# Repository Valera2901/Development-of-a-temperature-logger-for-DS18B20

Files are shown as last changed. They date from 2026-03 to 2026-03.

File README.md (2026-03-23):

# Development-of-a-temperature-logger-for-DS18B20

Организовать мониторинг температуры в геофизической обсерватории (на примере обсерватории Арти Института геофизики УрО РАН).
Создать устройство на основе микроконтроллера, к которому подключаются несколько температурных датчиков (DS18B20), расположенных в разных местах (вне помещения, внутри помещения, подключен к корпусу измерительного прибора и тд). Устройство должно функционировать автономно, без подключения к компьютеру. При включении питания, устройство должно автоматически записывать принимаемые данные с термодатчиков в файл на SD-карту. Скачивание данных можно организовать несколькими способами: 

1\. при нахождении в сети вайфай контроллер мог бы передавать данные на определенный сайт, 

2\. Можно подключить к микроконтроллеру плату LAN и подключить к локальной сети обсерватории, чтобы данные были доступны как обычный диск в сети.
Проект выполнен на 50% если реализованы следующие функции:
Запись результатов измерений на SD‑карту (без потерь).
Обеспечение актуального точного времени на часах при записи данных в файле
Проект выполнен на 75% если реализованы следующие функции:
Запись результатов измерений на SD‑карту (без потерь).
Обеспечение актуального точного времени на часах при записи данных в файле
просмотр и скачивание файлов данных, без необходимости прерывать измерения (wifi, bt, LAN, веб-интерфейс, сетевой диск, обоснованный выбор командой)
Проект выполнен на 100% если реализованы следующие функции:
Запись результатов измерений на SD‑карту (без потерь).
Обеспечение актуального точного времени на часах при записи данных в файле
просмотр и скачивание файлов данных, без необходимости прерывать измерения (wifi, bt, LAN, веб-интерфейс, сетевой диск, обоснованный выбор командой)
просмотр результатов текущих измерений. Выбрать удобный способ для этого (мобильное приложение, веб-интерфейс)

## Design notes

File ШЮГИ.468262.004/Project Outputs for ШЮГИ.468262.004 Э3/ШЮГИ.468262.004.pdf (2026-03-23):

| | ¹ äîêóì. | Ïîäï. | Äàòà | ØÞÃÈ.468262.004 Èçì. Ëèñò
Ðàçðàá. | Âøèâöåâ | | | Ëîããåð òåìïåðàòóðíûé | Ëèò. | Ëèñò | Ëèñòîâ
Ïðîâ. | | | | | | | | 1

Í.êîíòð.
Óòâ.

Äîêóìåíòàöèÿ

*) | ØÞÃÈ.468262.004 Ý3 | Ñõåìà ýëåêòðè÷åñêàÿ | *)A2, A4
| | ïðèíöèïèàëüíàÿ
À3 | ØÞÃÈ.468262.004 Ý4 | Ñõåìà ýëåêòðè÷åñêàÿ
| | ñîåäèíåíèé
À4 | ØÞÃÈ.468262.004 ÏÝ3 | Ïåðå÷åíü ýëåìåíòîâ
À4 | ØÞÃÈ.468262.004 ÏÇ | Ïîÿñíèòåëüíàÿ çàïèñêà
| ØÞÃÈ.468262.004 Ò12Ì | Äàííûå ïðîãðàììèðîâàíèÿ

Ñáîðî÷íûå åäèíèöû

À4 | 1 | ØÞÃÈ.685711.470 | Êàáåëü 1-wire | 3
A4 | 2 ØÞÃÈ.758724.220 | | Ìîäóëü âû÷èñëèòåëüíûé | 1
A4 | 3 ØÞÃÈ.758724.224 | | Ìîäóëü äàò÷èêà | 1
| 4 ØÞÃÈ.758724.224-01 | | Ìîäóëü äàò÷èêà | 1
| 5 ØÞÃÈ.758724.224-02 | | Ìîäóëü äàò÷èêà | 1

Ôîðìàò
Çîíà
Ïîç.
Îáîçíà÷åíèå | Íàèìåíîâàíèå

Êîë.

Ïðèìå-
÷àíèå
Êîïèðîâàë | Ôîðìàò A4

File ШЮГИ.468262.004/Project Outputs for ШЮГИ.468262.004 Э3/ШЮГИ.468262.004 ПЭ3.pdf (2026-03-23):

## ØÞÃÈ.468262.004 ÏÝ3

Èçì. Ëèñò | | ¹ äîêóì. | Ïîäï. | Äàòà
Ðàçðàá. | Âøèâöåâ | | | Ëîããåð òåìïåðàòóðíûé Ïåðå÷åíü ýëåìåíòîâ | Ëèò. | Ëèñò | Ëèñòîâ
Ïðîâ. | | | | | | | | 1 | 4

Í.êîíòð.
Óòâ.
A1 | Óñòðîéñòâî FJM10K YDELEKS | 1
| Êîíäåíñàòîðû 0603 Thunder
| Êîíäåíñàòîðû JCK JB Capacitors
C1, C2 0603B104J500CT | | 2
C3 | JCK1E100M050054 | 1
C4 | JCK1E470M063054 | 1
C5...C7 0603B104J500CT | | 3
C8 | JCK1E220M063054 | 1
C9 | JCK1C221M080105 | 1
C10...C14 0603B104J500CT | | 5
| Ìèêðîñõåìû
DA1 | XL6009E1 Shanghai Xinlong
| Semiconductor Technology Co., Ltd | 1
DD1 | ESP32-S3-WROOM1 MON16R8 Espressif | 1
DD2 | PCF8574T Philips Semiconductors | 1
DD3 | NEO-6M U-Blox | 1
DD4 | DS3231S# Maxim Integrated Products | 1
DD5 | 24AA32AT-I/ST Microchip Technology | 1

G1, G2 Ýëåìåíò ïèòàíèÿ ëèòèåâûé GPCR2032-7C1
| GP batteries | 2
| Îïòîýëåêòðîíèêà
HG1 | BCB2004-03-LW-SNMWD Blaze Display Technology | 1
HL1 | FYLS-0603GC Ningbo Foryard Optoelectronics | 1

Ïîç.
îáîçíà-
÷åíèå
Íàèìåíîâàíèå | Êîë. Ïðèìå÷àíèå

## ØÞÃÈ.468262.004 ÏÝ3

Ëèñò
2 Èçì. Ëèñò | ¹ äîêóì. | Ïîäï. | Äàòà
| Êàòóøêè èíäóêòèâíîñòè
L1 | 7448991470 Wurth Elektronik | 1
L2 | LQM21DN220N00L Murata Electronics | 1
| Ðåçèñòîðû Ð1-12 ÀÁØÊ.434110.023 ÒÓ
| Ðåçèñòîðû ÍÐ1-86-6 ØÊÀÁ.434110.039 ÒÓ
| Ðåçèñòîðû 3362P Bourns
R1...R3 Ð1-12-0,063-10 êOì±2 %-Ò-Ë-Ì | | 3
R4 | ÍÐ1-86-6-10 êÎì±1 %-Ì-"À" | 1
R5 | Ð1-12-0,063-10 êOì±2 %-Ò-Ë-Ì | 1
R6 | Ð1-12-0,063-86,6 êOì±2 %-Ò-Ë-Ì | 1
R7 | ÍÐ1-86-6-10 êÎì±1 %-Ì-"À" | 1
R8 | 3362P-1-103LF | 1
R9, R10 Ð1-12-0,063-22,1 Oì±2 %-Ò-Ë-Ì | | 1
R11 | Ð1-12-0,063-1 êOì±2 %-Ò-Ë-Ì | 1
R12 | Ð1-12-0,125-22,1 Oì±2 %-Ò-Ë-Ì | 1
R13 | Ð1-12-0,063-1 êOì±2 %-Ò-Ë-Ì | 1
R14 | ÍÐ1-86-6-10 êÎì±1 %-Ì-"À" | 1
R15 | Ð1-12-0,063-1 êOì±2 %-Ò-Ë-Ì | 1
| Âûêëþ÷àòåëè
SA1 | MTS-103-C3 Massuse Ltd. | 1
SB1, SB2 KLS7-TS3401-2.5-250-B
| KLS Electronics Co., Ltd. | 2
| Äèîäû
VD1 | VS-50WQ03FN-M3 Vishay Intertechnology Inc. 1
VD2, VD3 LL4148 Diotec Semiconductor | | 1
VT1 | Òðàíçèñòîð BC847 NXP Semiconductors | 1

| | | 3 Èçì. Ëèñò
¹ äîêóì. | Ïîäï. | Äàòà
WA1 | Àíòåííà GNSS Ceramic Antenna Waveshare
| International Limited | 1
| Ñîåäèíåíèÿ êîíòàêòíûå
X1 | DS1069-4MRW6XB Connfly electronic | 1
X2 | 1050017-0001 Molex | 1
X3 | DS-261A-PA9T-NB-210 Dragon City Industries | 1
X4 | TFP09-2-12B Shenzhen Chipskey Technology Co., Ltd. 1
X5 | DS-261A-PA9T-NB-210 Dragon City Industries | 1
A1, A2 1 Ïîíèæàþùèé ïðåîáðàçîâàòåëü íàïðÿæåíèÿ | 2
| Êîíäåíñàòîðû
C15 | 0603B104J500CT Thunder | 1
C16 | 0603B561J500CT Thunder | 1
C17 | JCK1C100M040054 JB Capacitors | 1
DA2 | Ìèêðîñõåìà MC34063ADG ON Semiconductor | 1
L3 | Êàòóøêà èíäóêòèâíîñòè CDRH74NP-101MC-B
| SUMIDA CORPORATION | 1
| Ðåçèñòîðû
R16 | CRL1206-FW-R220ELF Bourns | 1
R17 | Ð1-12-0,25-1,21 êOì±2 %-Ò-Ë-Ì
| ÀÁØÊ.434110.023 ÒÓ | 1
R18 | Ð1-12-0,25-3,65 êOì±2 %-Ò-Ë-Ì
| ÀÁØÊ.434110.023 ÒÓ | 1
VD4 | Äèîä 10MQ040 Sunmate Electronics | 1

| | | 4 Èçì. Ëèñò
¹ äîêóì. | Ïîäï. | Äàòà
A3...A5 2 Ìîäóëü äàò÷èêà | 3
C18 | Êîíäåíñàòîð 0603B104J500CT Thunder | 1
DD6 | Ìèêðîñõåìà DS18B20
| UTD Semiconductor Co.,Ltd | 1

X6, X7 Ñîåäèíåíèå êîíòàêòíîå DS1021-01-1*3SSF112
| Connfly electronic | 2

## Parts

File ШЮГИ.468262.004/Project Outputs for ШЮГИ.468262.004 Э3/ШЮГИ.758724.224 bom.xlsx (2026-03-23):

Line # | Designator | Quantity | ТИП | ValueBOM
 | A3_C18, A4_C18, A5_C18 | 3 | Конденсатор | 0603B104J500CT Thunder
 | A3_DD6, A4_DD6, A5_DD6 | 3 | Микросхема | DS18B20 UTD Semiconductor Co.,Ltd
 | A3_X7, A4_X7, A5_X7 | 6 | Соединитель | DS1021-01-1*3SSF112 Connfly electronic

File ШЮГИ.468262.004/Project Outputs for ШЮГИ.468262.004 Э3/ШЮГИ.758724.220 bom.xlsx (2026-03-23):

Line # | Designator | Quantity | ТИП | ValueBOM | Type2
10 | A1 | 1 | Устройтсво | KY-023 Aitewin Robot | A
11 | A1_C15, A2_C15, C1, C2, C5...C7, C10...C14 | 12 | Конденсатор | 0603B104J500CT Thunder | C
12 | A1_C16, A2_C16 | 2 | Конденсатор | 0603B561J500CT Thunder | C
13 | A1_C17, A2_C17 | 2 | Конденсатор | JCK1C100M040054 JB Capacitors | C
14 | C9 | 1 | Конденсатор | JCK1C221M080105 JB Capacitors | C
15 | C3 | 1 | Конденсатор | JCK1E100M050054 JB Capacitors | C
16 | C8 | 1 | Конденсатор | JCK1E220M063054 JB Capacitors | C
17 | C4 | 1 | Конденсатор | JCK1E470M063054 JB Capacitors | C
18 | DD5 | 1 | Микросхема | 24AA32AT-I/ST Microchip Technology | D
19 | DD4 | 1 | Микросхема | DS3231S# Maxim Integrated Products | D
20 | DD1 | 1 | Микросхема | ESP32-S3-WROOM1 MON16R8 Espressif | D
21 | A1_DA2, A2_DA2 | 2 | Микросхема | MC34063ADG ON Semiconductor | D
22 | DD3 | 1 | Микросхема | NEO-6M U-Blox | D
23 | DD2 | 1 | Микросхема | PCF8574T Philips Semiconductors | D
24 | DA1 | 1 | Микросхема | XL6009E1 Shanghai Xinlong Semiconductor Technology Co., Ltd | D
25 | G1, G2 | 2 | Батарейка | GPCR2032-7C1 GP Batteries | G
26 | HG1 | 1 | Оптоэлектроника | BCB2004-03-LW-SNMWD Blaze Display Technology | H
27 | HL1 | 1 | Оптоэлектроника | FYLS-0603GC Ningbo Foryard Optoelectronics | H
28 | L1 | 1 | Дроссель | 7448991470 Würth Elektronik | L
29 | A1_L3, A2_L3 | 2 | Дроссель | CDRH74NP-101MC-B SUMIDA CORPORATION | L
30 | L2 | 1 | Дроссель | LQM21DN220N00L Murata Electronics | L
31 | R8 | 1 | Резистор | 3362P-1-103LF Bourns | R
32 | A1_R16, A2_R16 | 2 | Резистор | CRL1206-FW-R220ELF Bourns | R
33 | R4, R7, R14 | 3 | Резистор | НР1-86-6-10 кОм±1 %-М-«А» ШКАБ.434110.039 ТУ | R
34 | R11, R13, R15 | 3 | Резистор | Р1-12-0,063-1 кОм±2 %-Т-Л-М АБШК.434110.023 ТУ | R
35 | R1...R3, R5 | 4 | Резистор | Р1-12-0,063-10 кОм±2 %-Т-Л-М АБШК.434110.023 ТУ | R
36 | R9, R10 | 2 | Резистор | Р1-12-0,063-22,1 Ом±2 %-Т-Л-М АБШК.434110.023 ТУ | R
37 | R6 | 1 | Резистор | Р1-12-0,063-86,6 кОм±2 %-Т-Л-М АБШК.434110.023 ТУ | R
38 | R12 | 1 | Резистор | Р1-12-0,125-22,1 Ом±2 %-Т-Л-М АБШК.434110.023 ТУ | R
39 | A1_R17 | 1 | Резистор | Р1-12-0,25-1,21 кОм±2 %-Т-Л-М АБШК.434110.023 ТУ | R
40 | A1_R18 | 1 | Резистор | Р1-12-0,25-3,65 кОм±2 %-Т-Л-М АБШК.434110.023 ТУ | R
41 | A2_R17 | 1 | Резистор | Р1-12-0,25-1 кОм±2 %-Т-Л-М АБШК.434110.023 ТУ | R
42 | A2_R18 | 1 | Резистор | Р1-12-0,25-1,65 кОм±2 %-Т-Л-М АБШК.434110.023 ТУ | R
43 | SB1, SB2 | 2 | Выключатели | KLS7-TS3401-2.5-250-B KLS Electronics Co., Ltd. | S
44 | SA1 | 1 | Выключатели | MTS-103-C3 Massuse Ltd. | S
45 | A1_VD4, A2_VD4 | 2 | Полупроводник | 10MQ040 Sunmate Electronics | V
46 | VT1 | 1 | Полупроводник | BC847 NXP Semiconductors | V
47 | VD2, VD3 | 2 | Полупроводник | LL4148 Diotec Semiconductor | V
48 | VD1 | 1 | Полупроводник | VS-50WQ03FN-M3 Vishay Intertechnology Inc. | V
49 | WA1 | 1 | Антенна | GNSS Ceramic Antenna Waveshare International Limited | W
50 | X2 | 1 | Соединитель | 1050017-0001 Molex | X
51 | A3_X6, A4_X6, A5_X6 | 3 | Соединитель | DS1021-01-1*3SSF112 Connfly electronic | X
52 | XH1 | 1 | Соединитель | DS1021-1*16SF11-B Connfly electronic | X
53 | XH2 |  | Соединитель | DS1023-1*16S21 Connfly electronic | X
54 | X1 | 1 | Соединитель | DS1069-4MRW6XB Connfly electronic | X
55 | X3, X5 | 2 | Соединитель | DS-261A-PA9T-NB-210 Dragon City Industries | X
56 | XG1, XG2 | 2 | Соединитель | KLS5-CR2032-01 KLS electronic co ltd | X
57 | X4 | 1 | Соединитель | TFP09-2-12B Shenzhen Chipskey Technology Co., Ltd. | X
58 | XW1 | 1 | Соединитель | U.FL-R-SMT-1 HIROSE ELECTRIC CO., LTD. | X

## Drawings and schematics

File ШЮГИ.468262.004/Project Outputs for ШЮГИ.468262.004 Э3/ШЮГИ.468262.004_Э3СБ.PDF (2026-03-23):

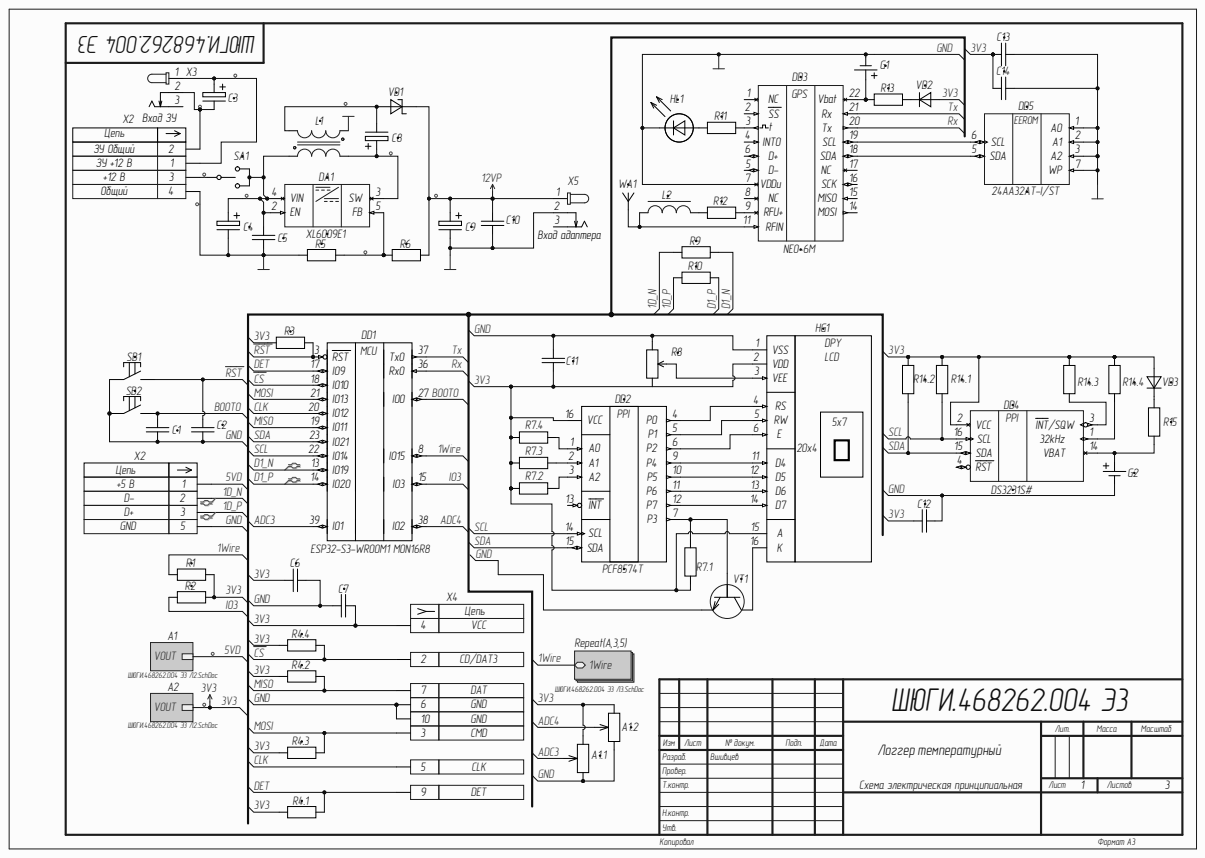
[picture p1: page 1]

DPY LCD

Цепь

4 | VCC

7 | DAT
6 | GND
10 | GND

ШЮГИ.468262.004 Э3

Логгер температурный Схема электрическая принципиальная | Лит. | Масса | Масштаб
Изм | Лист | № докум. | Подп. | Дата
Разраб. | | Вшивцев

Провер.
Т.контр. | | | | | Лист 1 | Листов 3

Н.контр.
Утв.

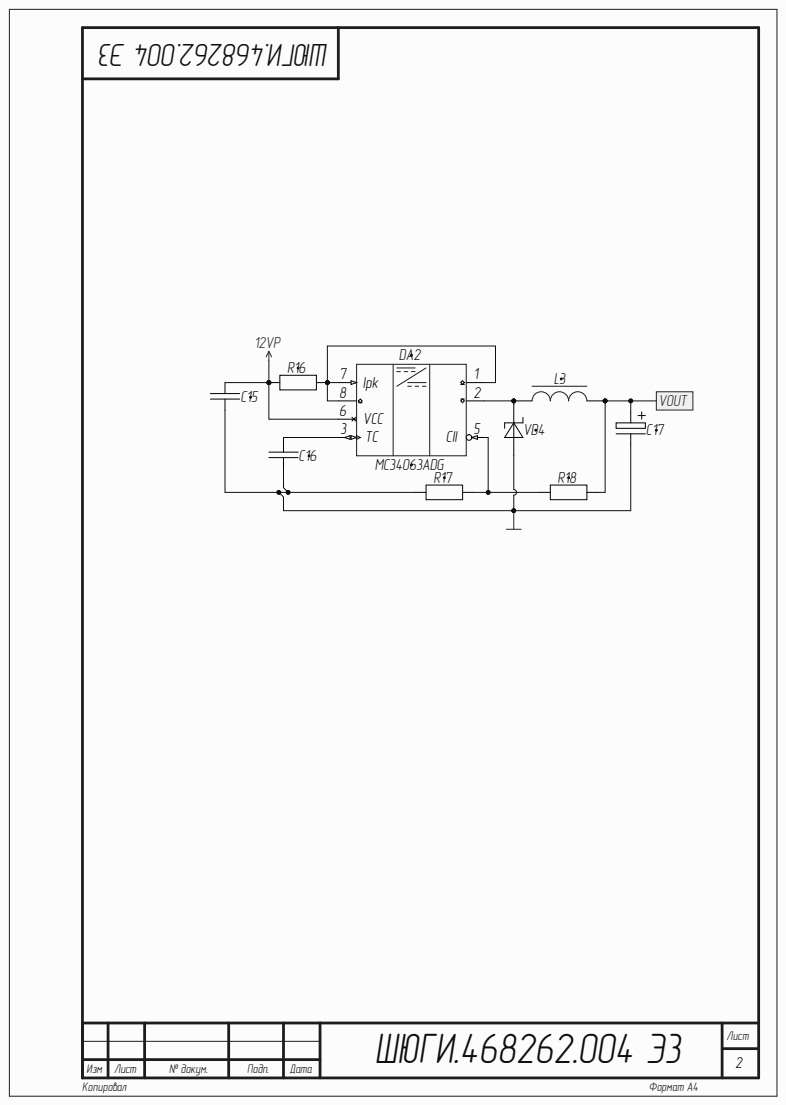
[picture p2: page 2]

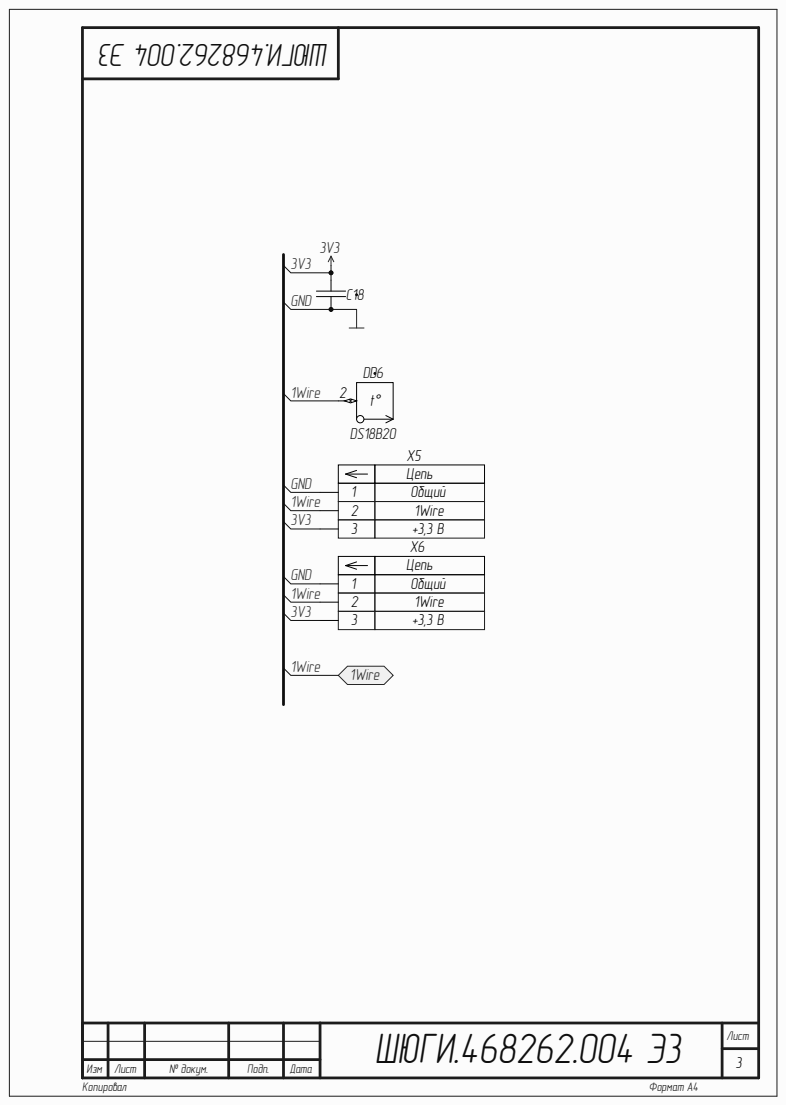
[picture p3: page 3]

Цепь GND

1 | Общий
2 | 1Wire
3 | +3,3 В

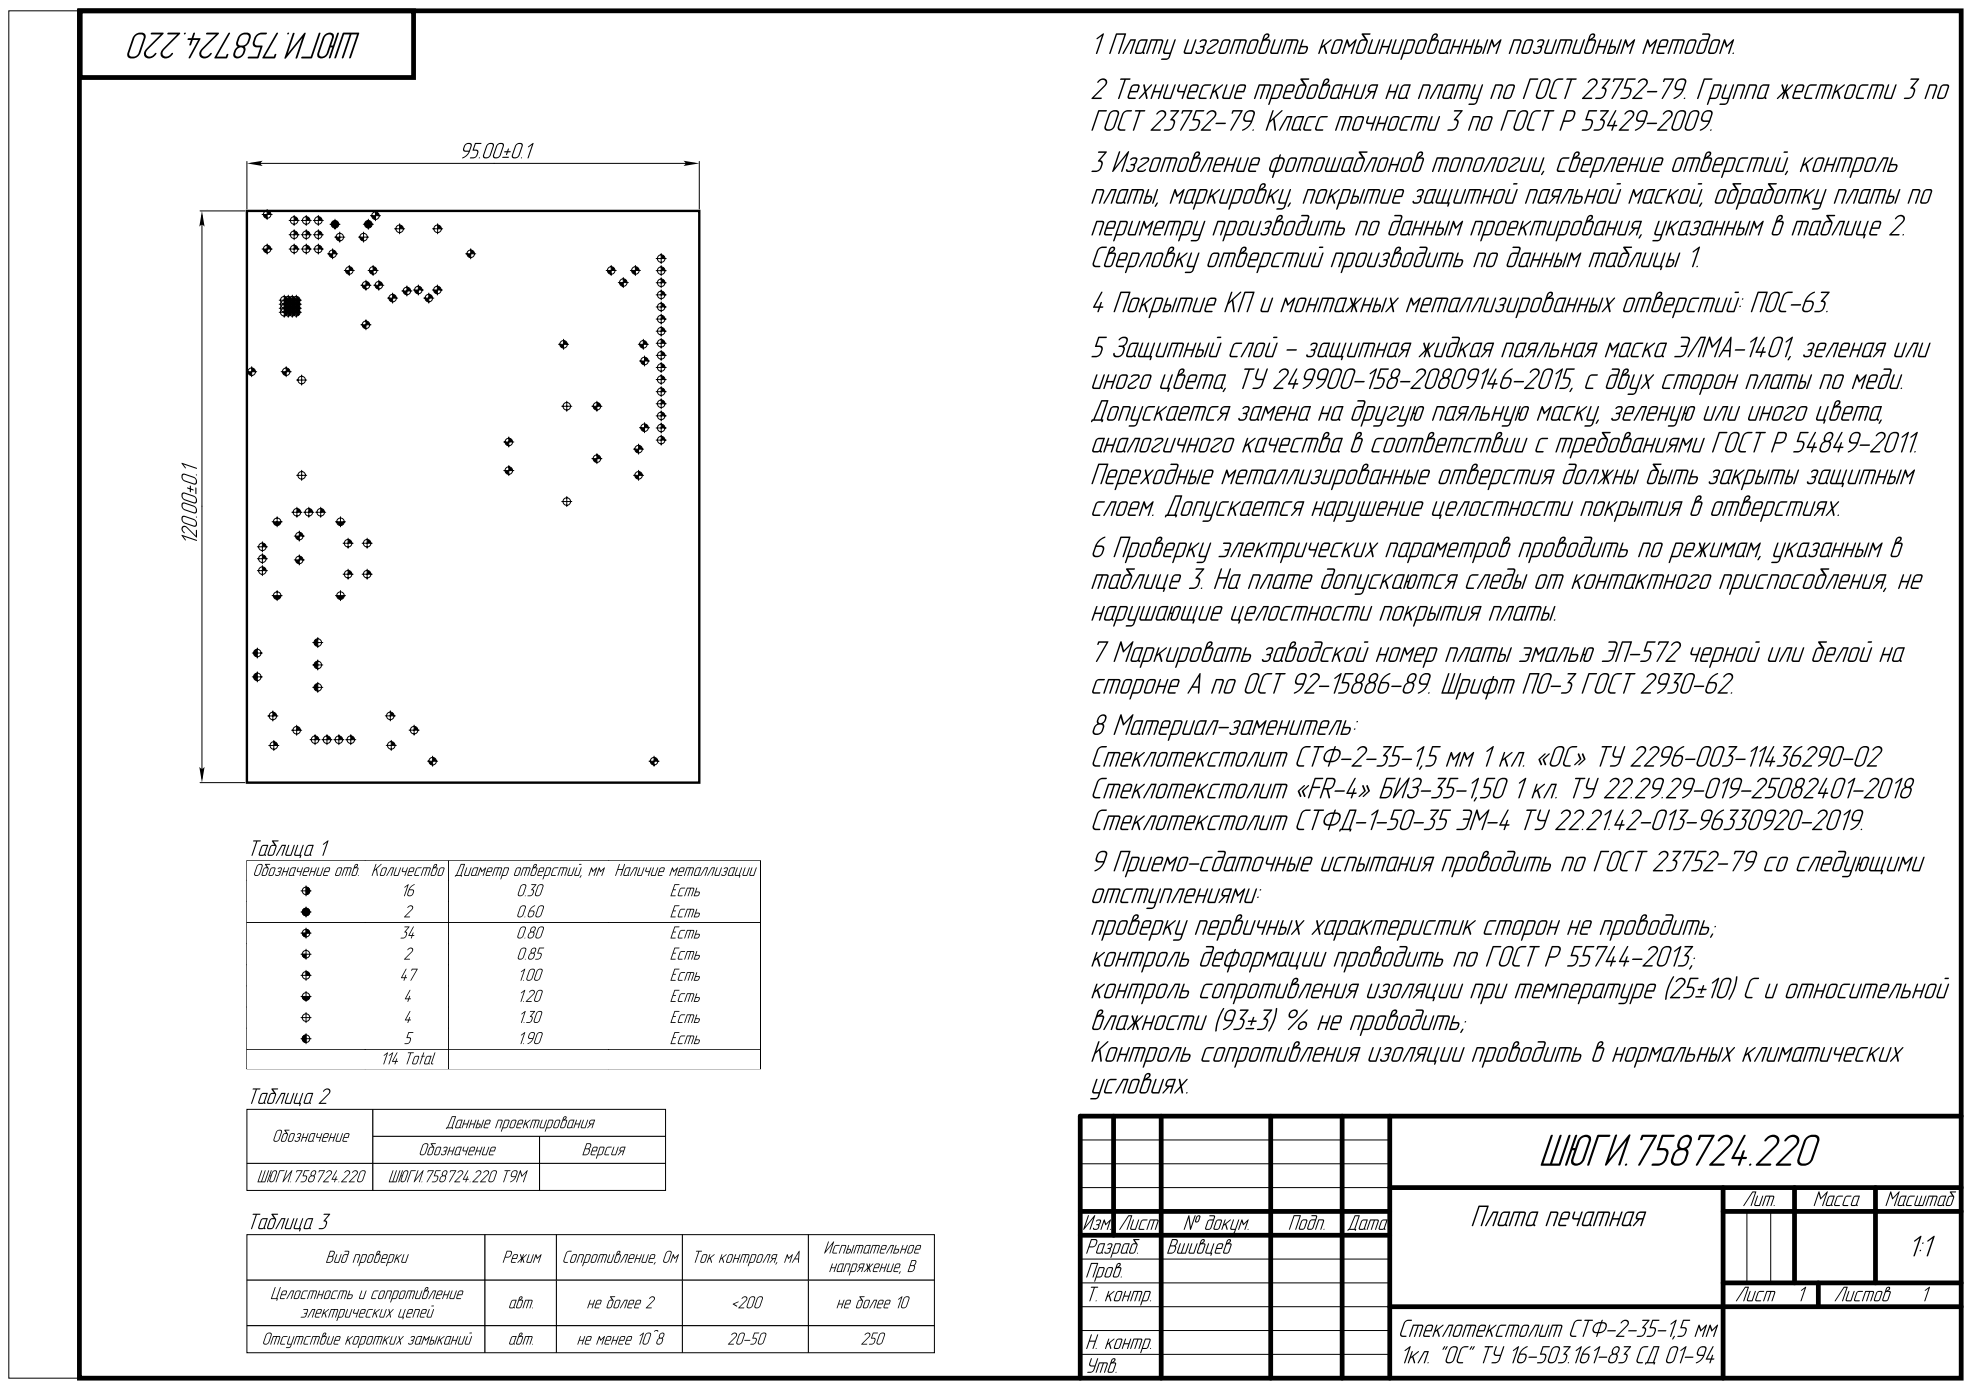
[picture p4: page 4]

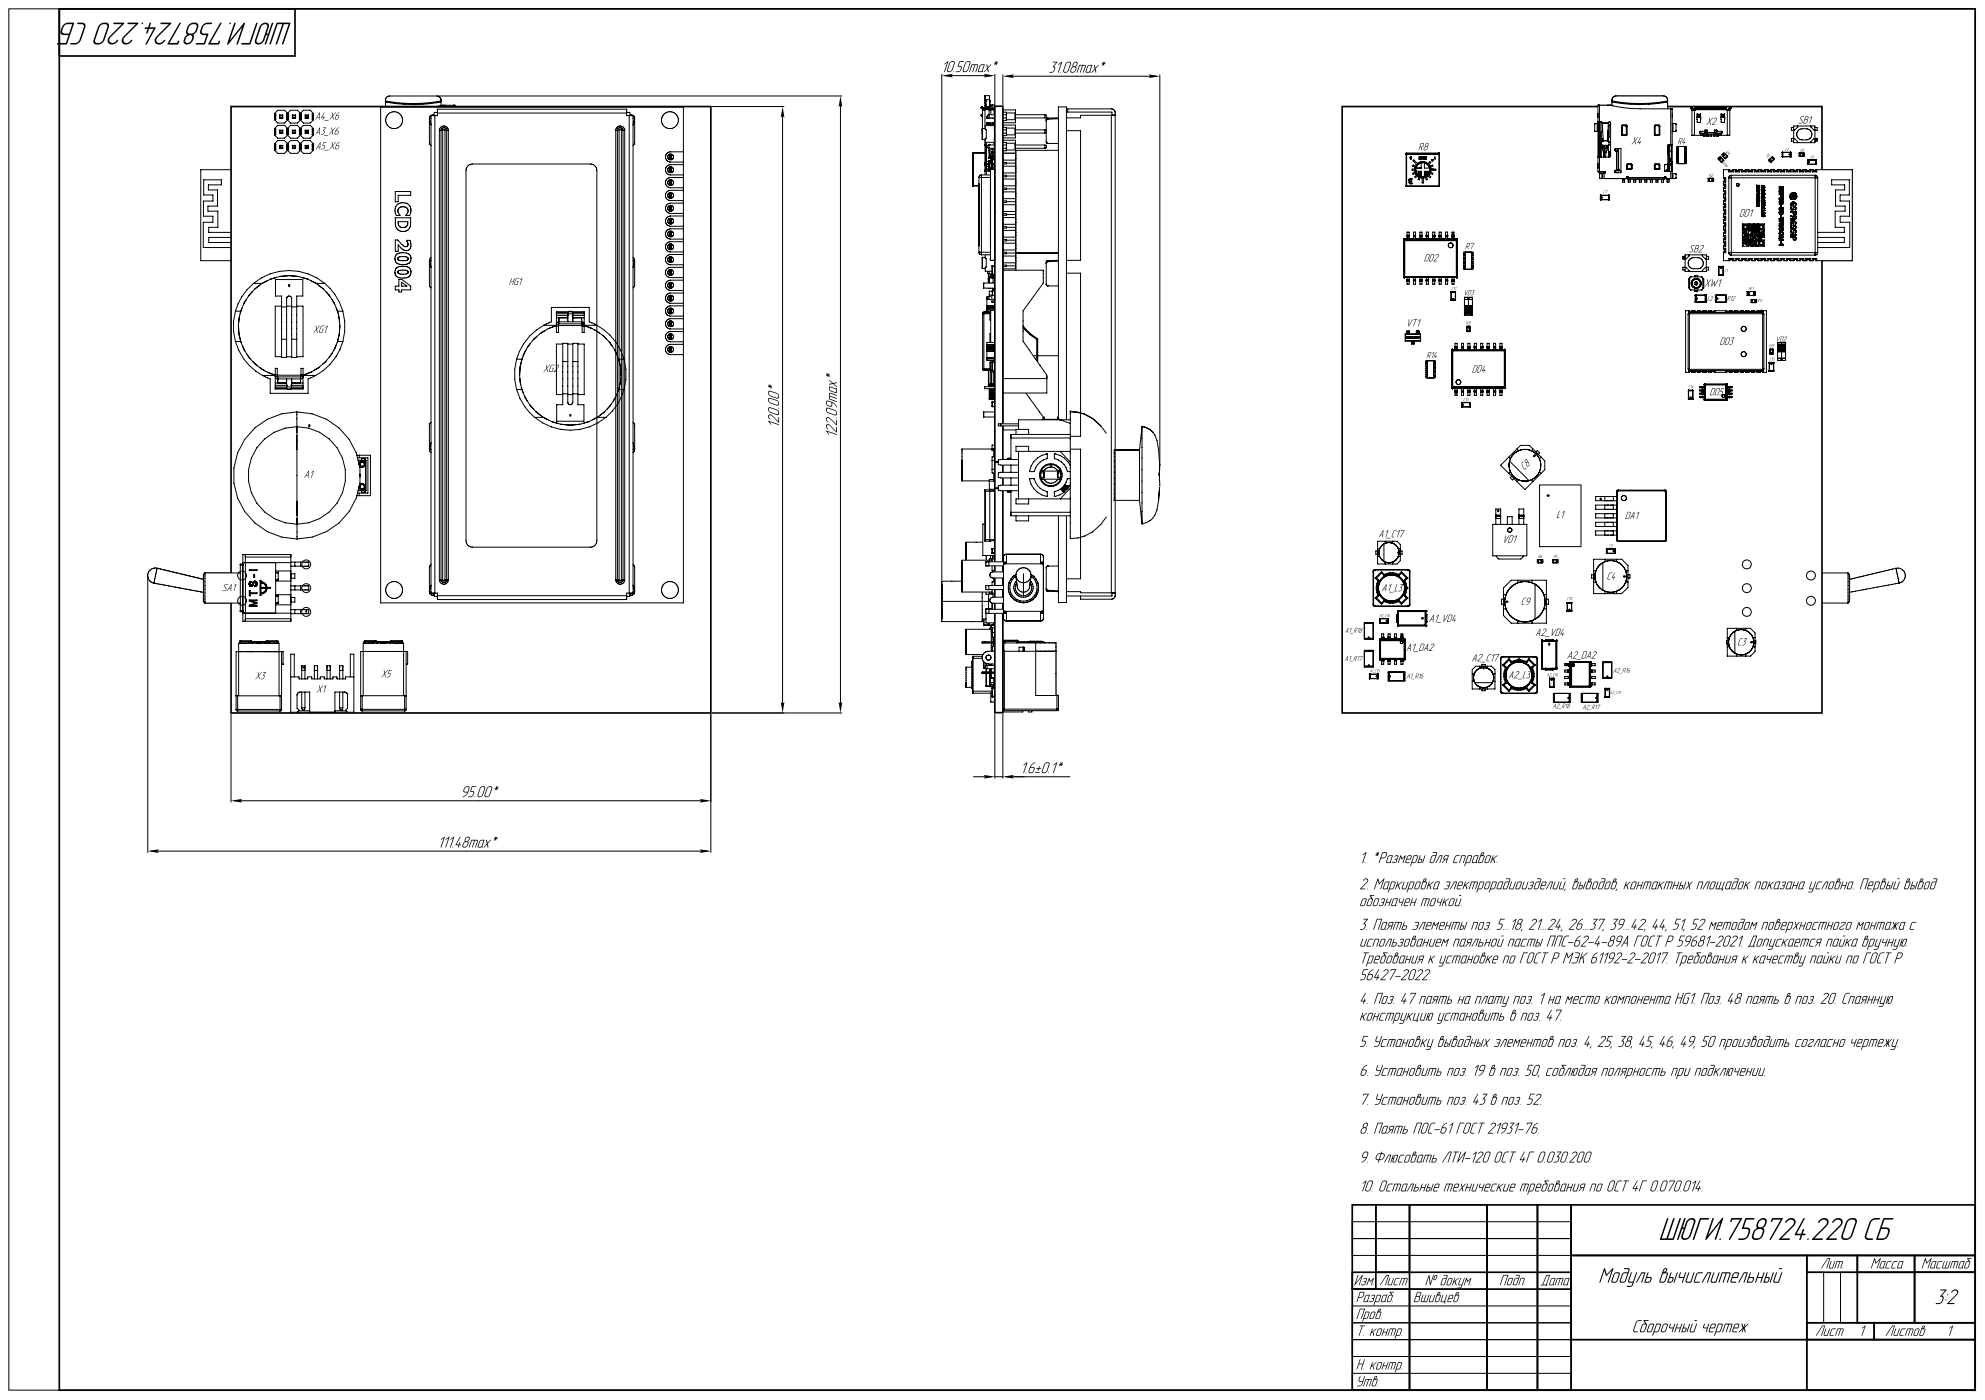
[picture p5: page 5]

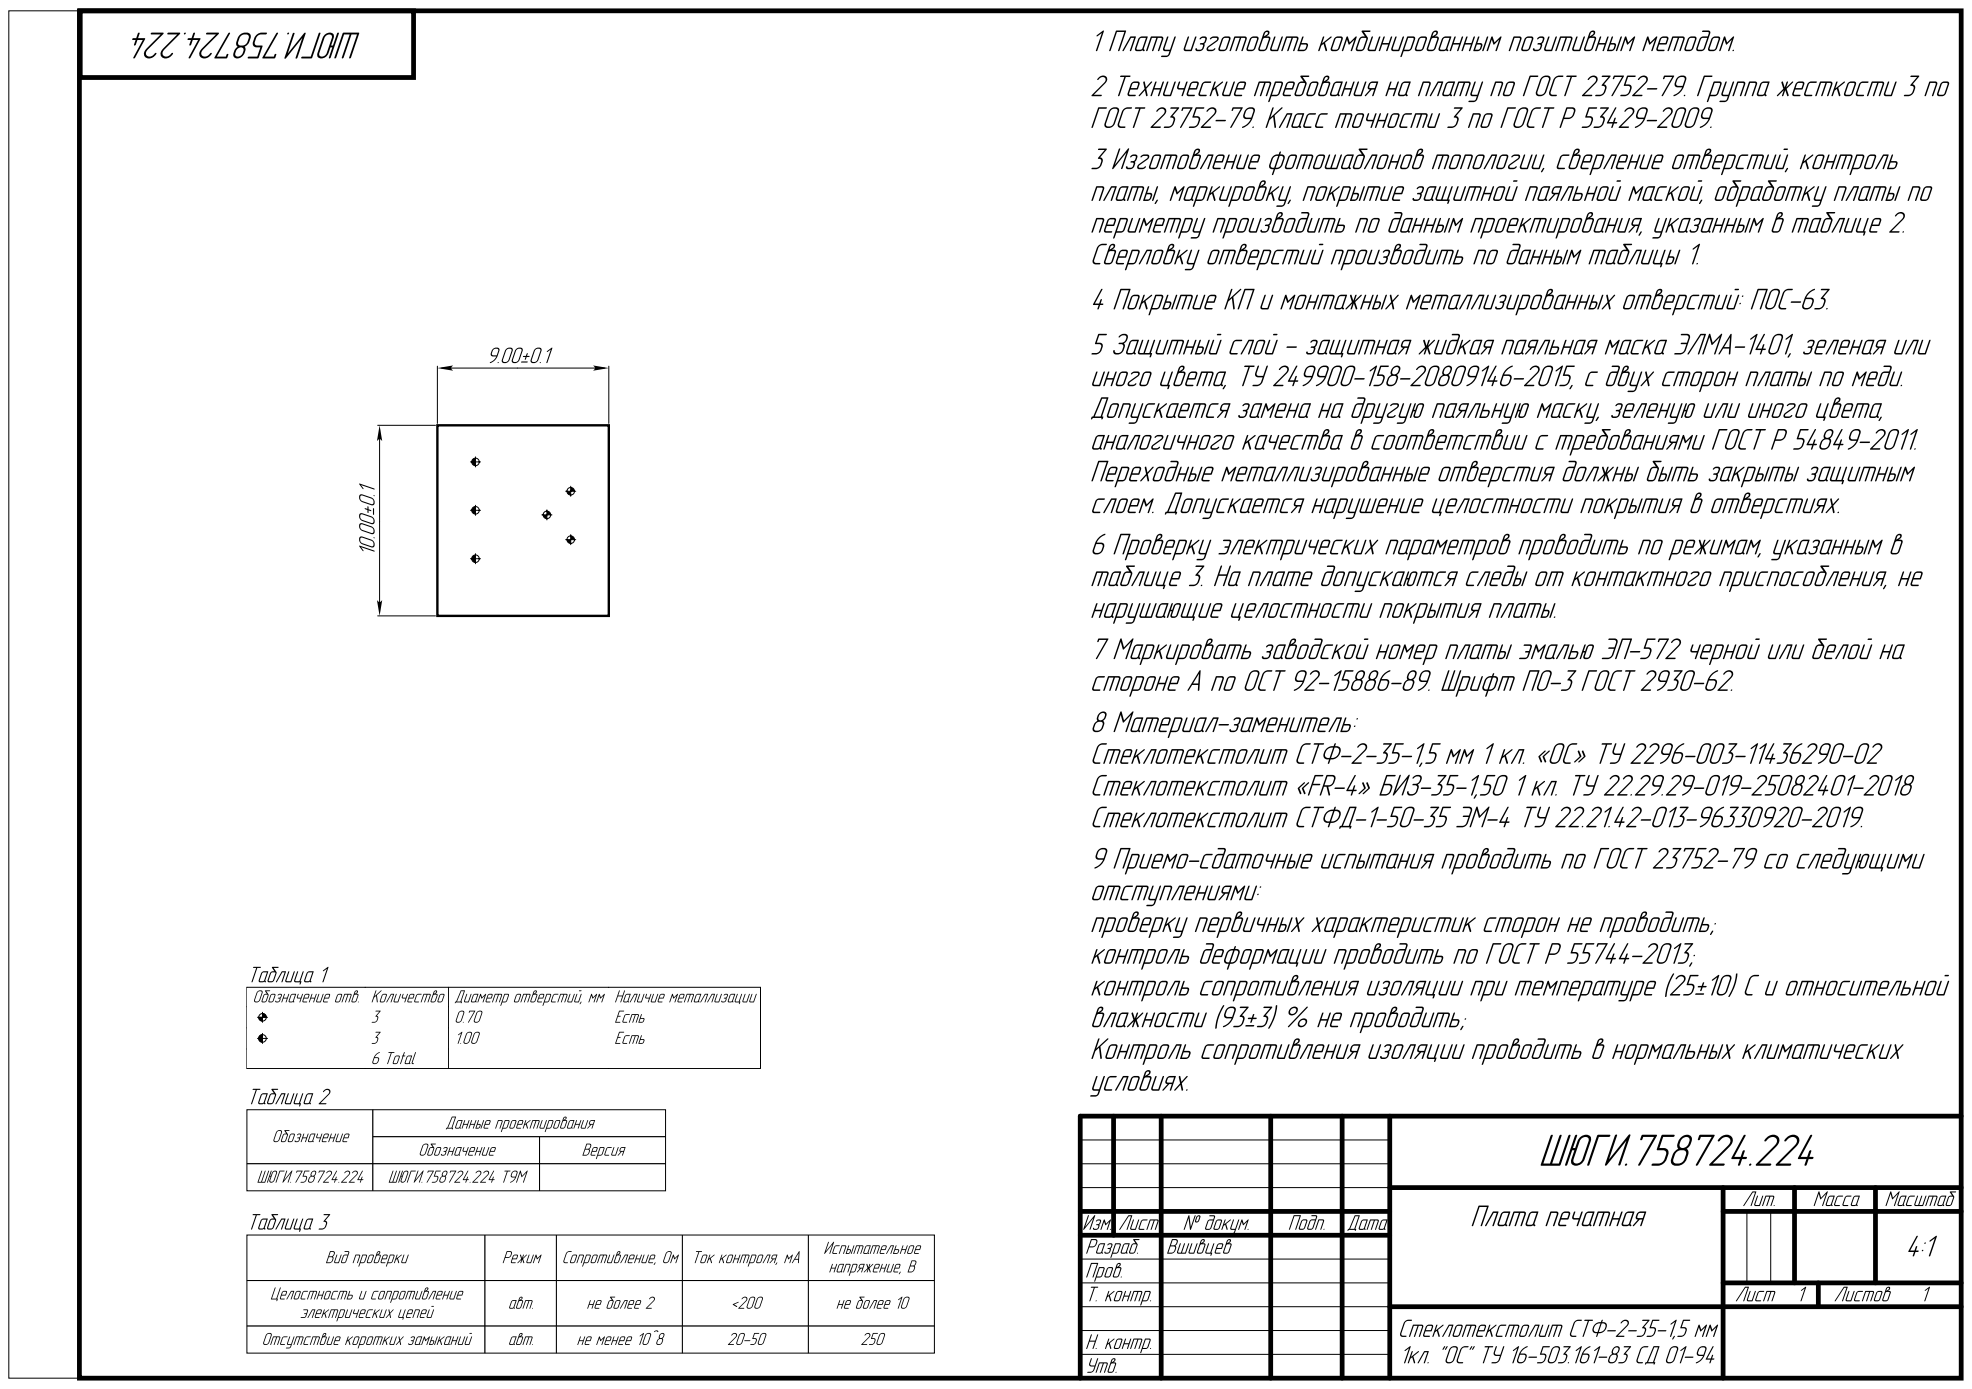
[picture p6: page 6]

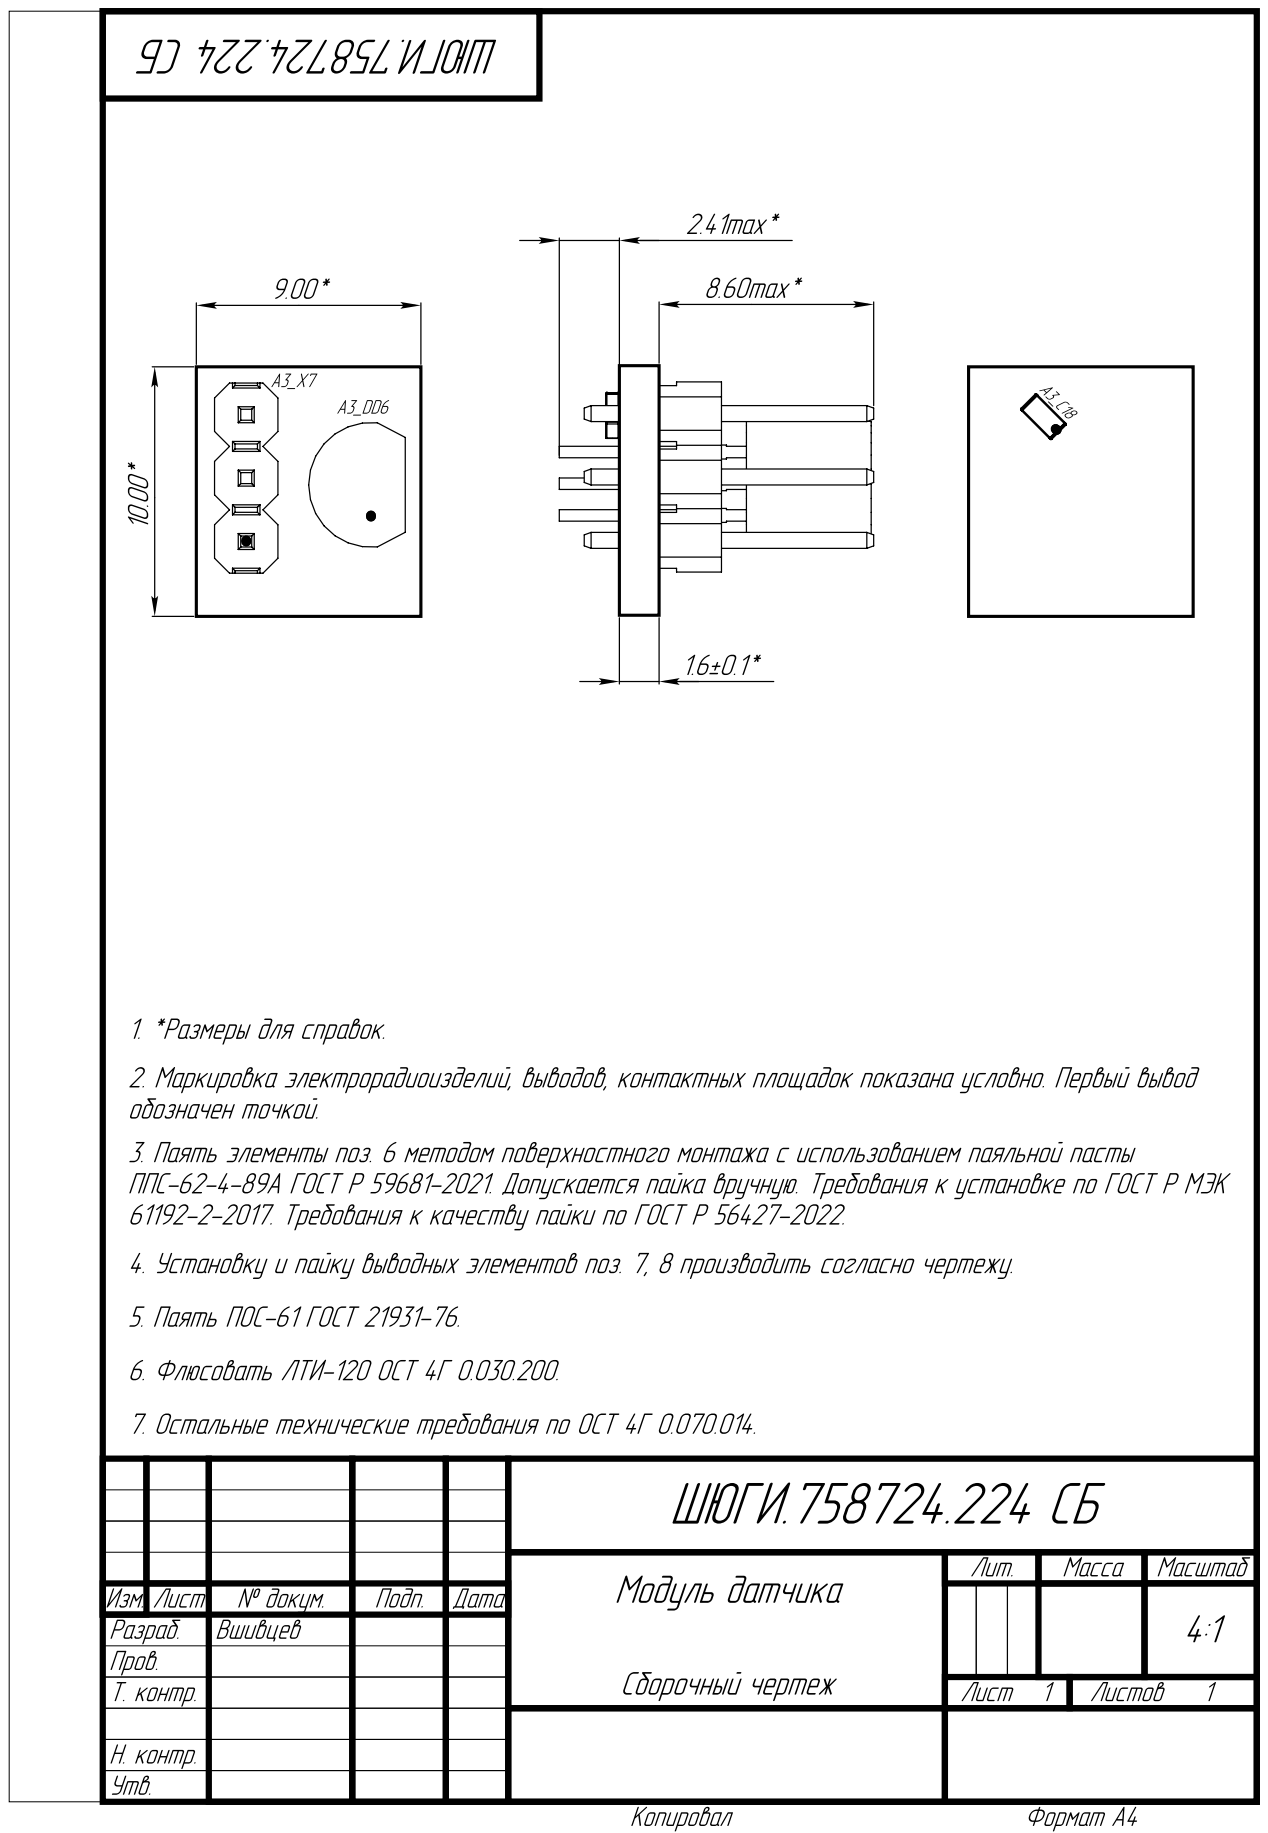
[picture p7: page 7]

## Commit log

2026-03-23 Create ШЮГИ.468262.004 Э3 Л1.SchDocPreview
2026-03-23 Create ШЮГИ.468262.004 Э3 Л2.SchDocPreview
2026-03-23 Create ШЮГИ.468262.004 Э3 Л3.SchDocPreview
2026-03-23 Create ШЮГИ.468262.004 Э3 Л4.SchDocPreview
2026-03-23 Create ШЮГИ.758724 19.03.2026 16-43-46.LOG
2026-03-23 Create Design Rule Check - ШЮГИ.758724.drc
2026-03-23 Create Design Rule Check - ШЮГИ.758724.html
2026-03-23 Create Плата вычислительная_ШЮГИ.758724.220.pdf
2026-03-23 Create Плата датчика_ШЮГИ.758724.224.pdf
2026-03-23 Create ШЮГИ.468262.004 ПЗ.docx
2026-03-23 Create ШЮГИ.468262.004 ПЭ3.pdf
2026-03-23 Create ШЮГИ.468262.004 Э3 bom.xlsx
    [ШЮГИ.468262.004 Э3 bom.xlsx]
2026-03-23 Create ШЮГИ.758724.220 bom.xlsx
    [ШЮГИ.758724.220 bom.xlsx]
2026-03-23 Create ШЮГИ.758724.224 bom.xlsx
    [ШЮГИ.758724.224 bom.xlsx]
2026-03-23 Create Плата вычислительная _ ШЮГИ.758724.220.spw
2026-03-23 Create Плата вычислительная _ ШЮГИ.758724.220.spw.bak
2026-03-23 Create Плата датчика _ ШЮГИ.758724.224.spw
2026-03-23 Create Плата датчика _ ШЮГИ.758724.224.spw.bak
2026-03-23 Create ШЮГИ.468262.004 ПЭ3.spw
2026-03-23 Create ШЮГИ.468262.004 ПЭ3.spw.bak
2026-03-23 Create ШЮГИ.468262.004 Э3 Л1.SchDoc
    [ШЮГИ.468262.004 Э3 Л1.SchDoc]
2026-03-23 Create ШЮГИ.468262.004 Э3 Л2.SchDoc
    [ШЮГИ.468262.004 Э3 Л2.SchDoc]
2026-03-23 Create ШЮГИ.468262.004 Э3 Л3.SchDoc
    [ШЮГИ.468262.004 Э3 Л3.SchDoc]
2026-03-23 Create ШЮГИ.468262.004 Э3.BomDoc
2026-03-23 Create ШЮГИ.468262.004 Э3.PRJPCB
    [ШЮГИ.468262.004 Э3.PRJPCB]
2026-03-23 Create ШЮГИ.468262.004 Э3.prjpcbStructure
2026-03-23 Create ШЮГИ.468262.004 Э3.PRJPCBVariants
2026-03-23 Create ШЮГИ.758724.220 Т9М.PcbDoc
2026-03-23 Create ШЮГИ.758724.220 Т9М.PCBDwf
2026-03-23 Create ШЮГИ.758724.220 Т9М_1.PCBDwf
2026-03-23 Create ШЮГИ.758724.224 Т9М.PcbDoc
    [ШЮГИ.758724.224 Т9М.PcbDoc]
2026-03-23 Create ШЮГИ.758724.224 Т9М.PCBDwf
2026-03-23 Create ШЮГИ.758724.224 Т9М_1.PCBDwf
